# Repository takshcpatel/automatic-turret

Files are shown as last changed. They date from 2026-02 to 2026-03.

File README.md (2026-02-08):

# BOB THE GUN
This is an automatic turret inspired by the tf2's engineer's sentry gun. It detects and shoots threats if they do not comply from warning. I have made this project to learn about CAD, mechanical, computer vision, software->hardware communication, etc.

## Links
YouTube :- [Quack Robotics](https://www.youtube.com/@QuackRobotics)

Instagram :- [@quackrobotics](https://www.instagram.com/quackrobotics)

OnShape :- [OnShape CAD View](https://cad.onshape.com/documents/a227c9c3e91dedc730053277/w/3ffe9ea86f039fb92ebcc4d6/e/9ef318677793f062c9bceb51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)

Hackclub Blueprint :- [Bob the Gun](https://blueprint.hackclub.com/projects/9715)

Hackclub Flavortown :- [Bob the Gun](https://flavortown.hackclub.com/projects/8451)

Image of gun

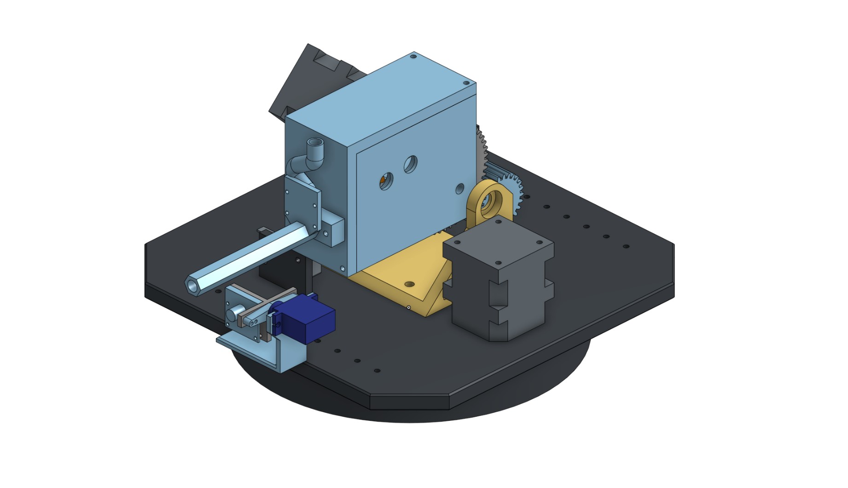
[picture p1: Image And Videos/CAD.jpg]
Image of CAD


## Working 
### Mechanical
This is an electric airsoft gun ( EAG ) type of mechanism mounted on a Pan / Tilt Mechanism. It is has a pan freedom of **∞**º and a tilt freedom of about 70-80º. Uses a lazy susan bearing for the infinite pan motion and the camera is connected to a SG-90 Servo for a independent tilt motion.

### Software 
The computer vision and calculations are done in the [RaspberryPi 5](https://www.raspberrypi.com/products/raspberry-pi-5/). It receives frames from the [RaspberryPi Camera 3 Wide](https://www.raspberrypi.com/products/camera-module-3/). (For now) It detects an object based on color (currently yellow) and calculates the direction to move. It has a deadzone system for determining when to shoot.

### Hardware controlling 
The Nema17 motors are controlled by an Arduino Uno with the CNC Shield V3. The Arduino is connected to the RPi using a standard USB Type A - USB Type B. The RPi sends G-Code like commands to the Arduino to control the motors. 

The human interface is controlled directly from the python script using either ethernet cable (restricts movement) or by Wi-Fi  local network, it works completely offline if you want it. 

### Power 
I have used a 12V+ 10000mAh Li-Po battery which connects to the CNC Shield and a XH-M404 Buck converter. The XH-M404 outputs 5.25V+ for the RaspberryPi and the Servo Motors.

## Use cases and applications
- If built with better parts and task specifics, it can be a use-case of riot-control. Sounds absurd but something like a paintball bullet or similar can be used to mark out people who are to be arrested for adding violence to the riot.

- Similarly, It can be used for drone defense if used with a guns / signal jammers / net launchers, etc.

- Can used for home security. This type can be equipped with rubber bullets so it hurts enough the robbers / intruders but doesn't. Of course it will have some kind of manual confirmation before shooting. 

- There can be other similar use case in many fields, mainly for security but more is yet to be discovered.

## Hardware List
|Item| Price  |
|--|--|
|RaspberryPi 5 8Gb  |99$|
|RaspberryPi Camera 3 Wide| 21$ |
|Arducam ToF Camera | 66$ |
|Orange NMC 11.1V 10000mAh | 44$ |
| 3D Printed Parts | Not accounted for
|Total|≈232$

## Libraries

- OpenCV

- NumPy

- PyQt5

## Licenses 
Just use it however you want in your project. This is just an educational project made so that I can learn different things. 

## Inspiration 
Cs2 Engineer

## Contact 
E-Mail :- takshcpatel@gmail.com
Discord :- mrcjoc

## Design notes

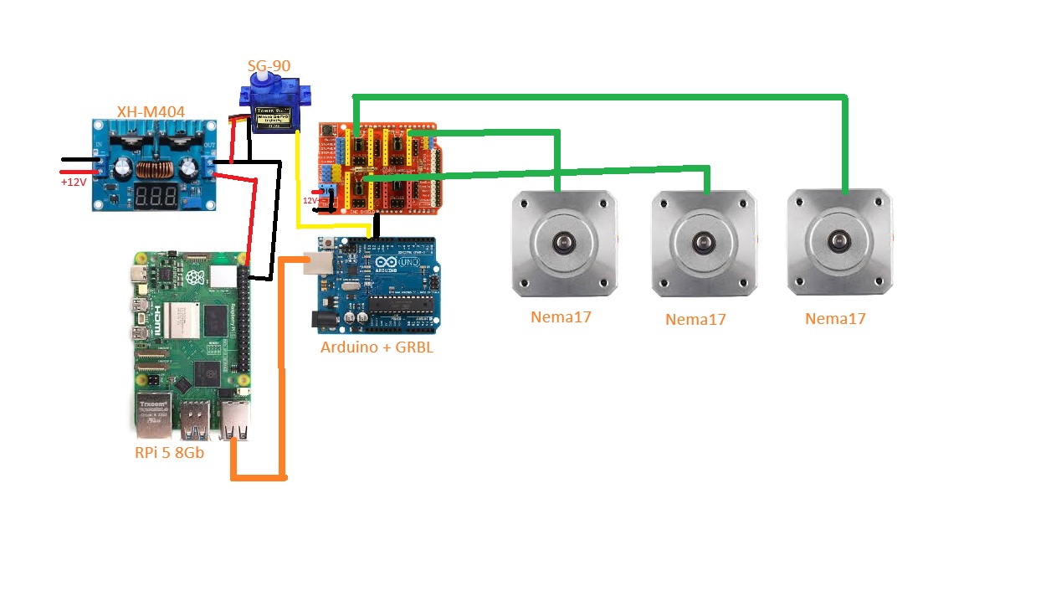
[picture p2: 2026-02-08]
Image And Videos/Pinout .jpg

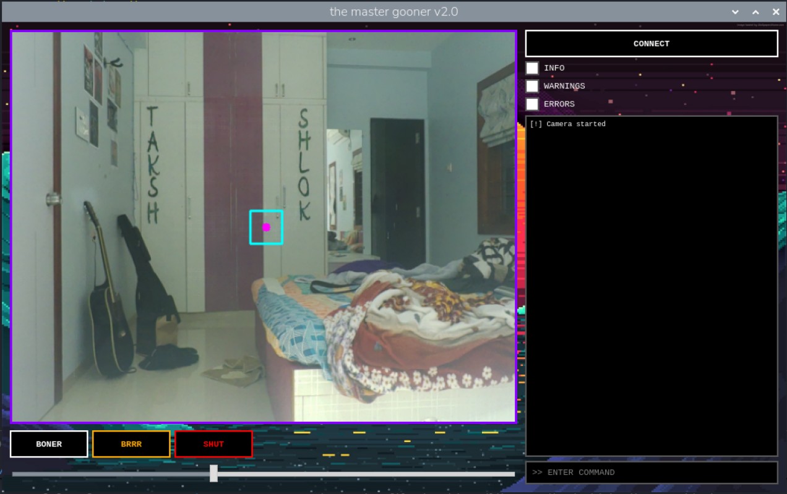
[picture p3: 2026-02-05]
Image And Videos/UI V2.0.jpg

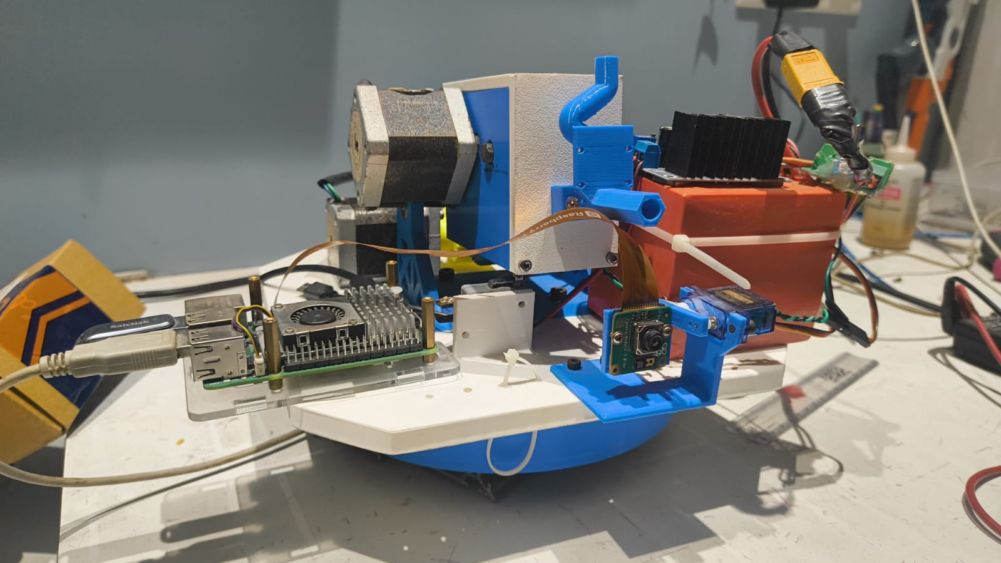
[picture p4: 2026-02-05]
Image And Videos/Photo #1.png

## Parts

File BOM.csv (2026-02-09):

Sr. No. | Name | Quantity | Price Single | Price Total USD | Price Total INR
1 | Raspberry Pi 5 8GB | 1 | ≈ 99.00$ | ≈ 99.00$ | 9000₹
2 | Raspberry Pi Camera 3 Wide | 1 | ≈ 21.00$ | ≈ 21.00$ | 1880₹
3 | Arducam Time of Flight Camera | 1 | ≈ 66.00$ | ≈ 66.00$ | 6000₹
4 | Orange NMC 18650 11.1V 10000mAh | 1 | ≈ 44.00$ | ≈ 44.00$ | 4000₹

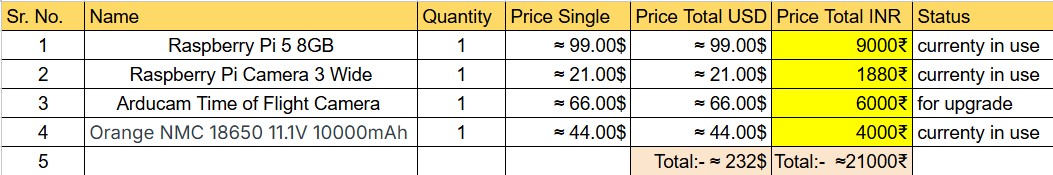
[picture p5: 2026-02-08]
BOM/BOM.jpg

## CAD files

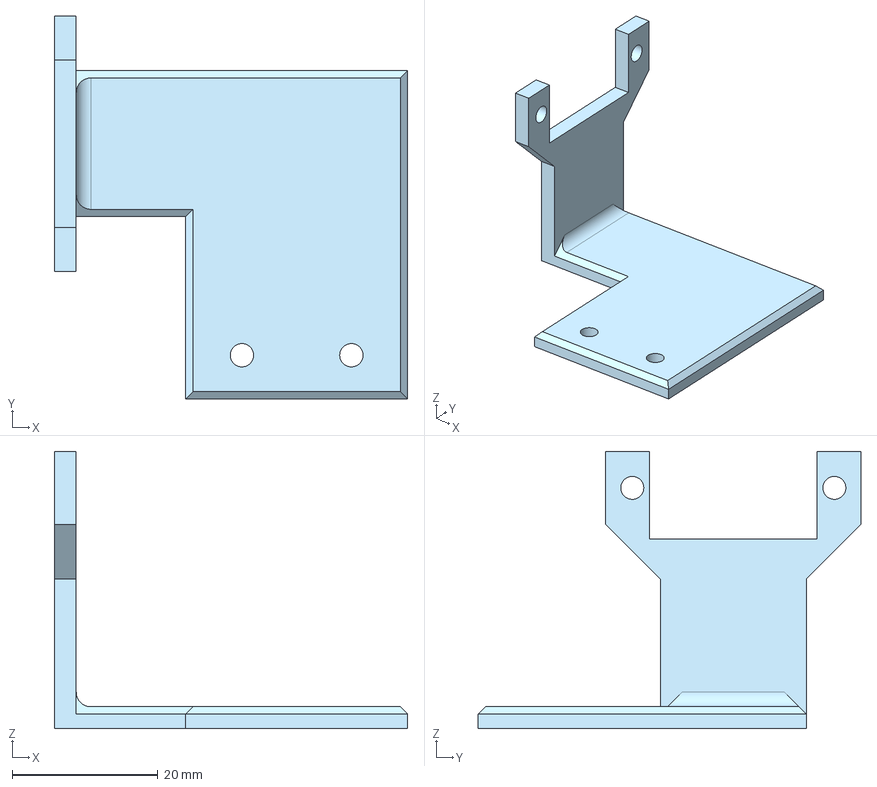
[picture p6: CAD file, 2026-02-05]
CAD Files/Pan/Camera hold/Servo Mount - Servo Base.step
48.4 x 52.5 x 38.0 mm

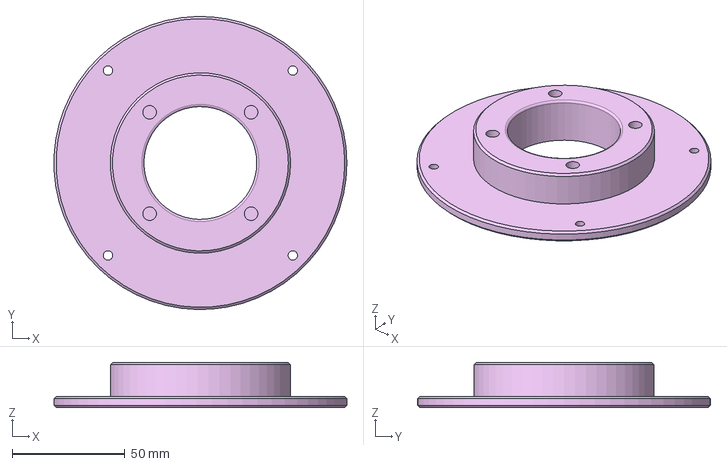
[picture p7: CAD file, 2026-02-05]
CAD Files/Pan/Moving Platform - Moving Platform.step
129.9 x 130.0 x 20.0 mm

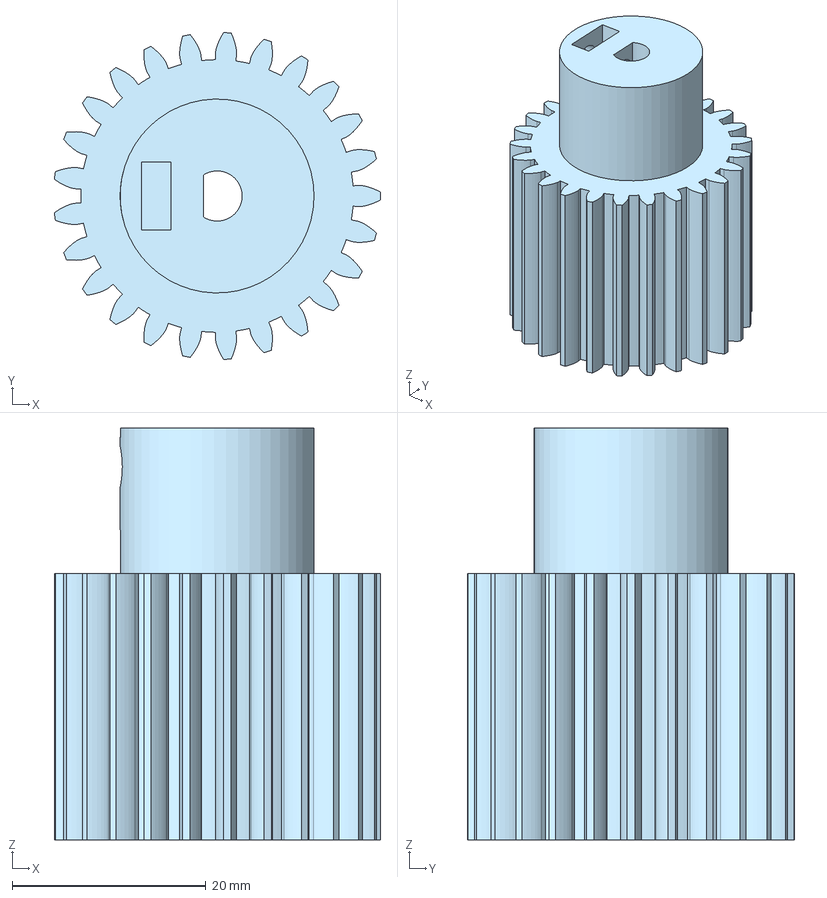
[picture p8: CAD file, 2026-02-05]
CAD Files/Tilt/Tilt Gear Train - Spur 1.25M 25T.step
33.7 x 33.7 x 42.5 mm

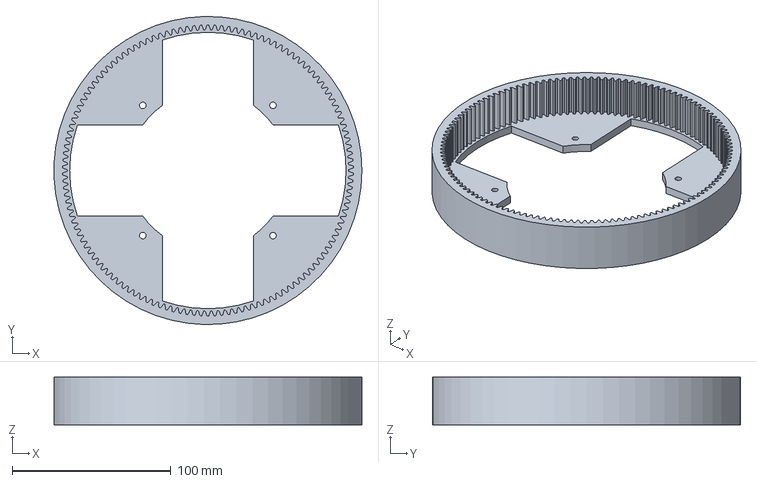
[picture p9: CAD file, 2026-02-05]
CAD Files/Pan/Base (1) - Base.step
193.9 x 193.9 x 30.0 mm

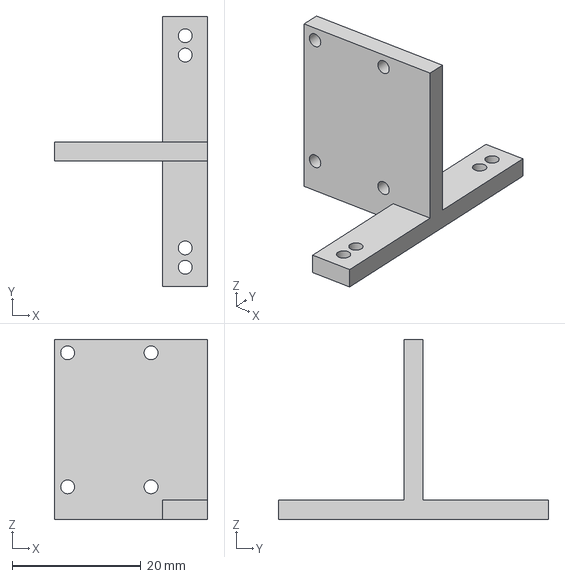
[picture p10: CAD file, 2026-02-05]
CAD Files/Pan/Camera hold/Servo Mount - Servo-Cam Mount.step
23.9 x 42.0 x 28.0 mm

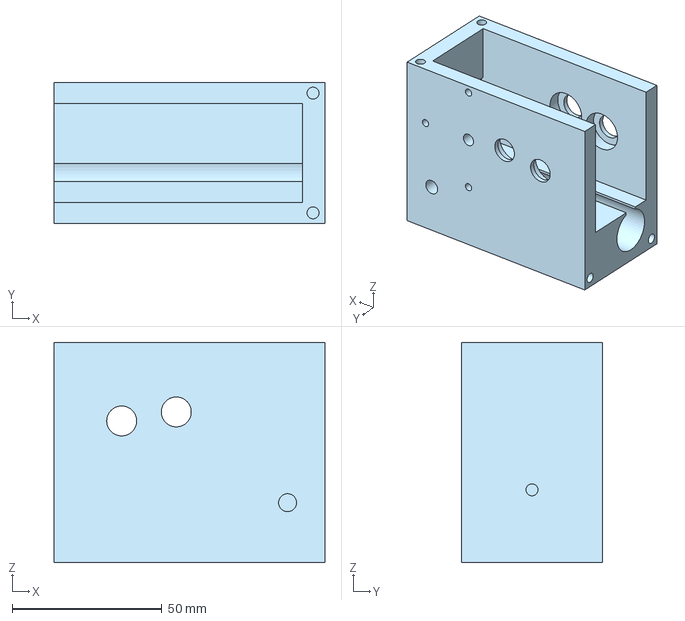
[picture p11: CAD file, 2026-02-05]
CAD Files/Tilt/Gun/Bottom Link - Body.step
90.5 x 47.0 x 73.5 mm

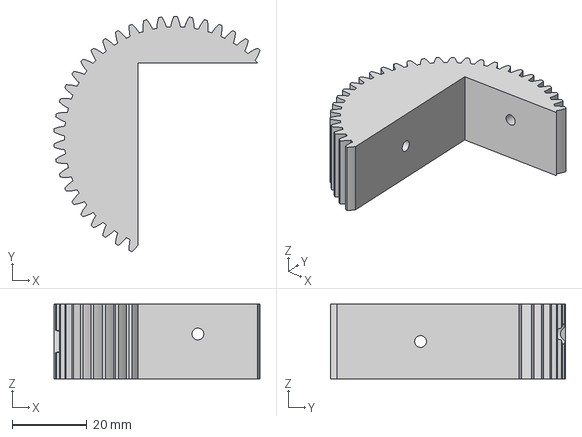
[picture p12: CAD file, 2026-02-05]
CAD Files/Tilt/Tilt Gear Train - Spur 1.25M 50T.step
55.0 x 62.9 x 20.0 mm

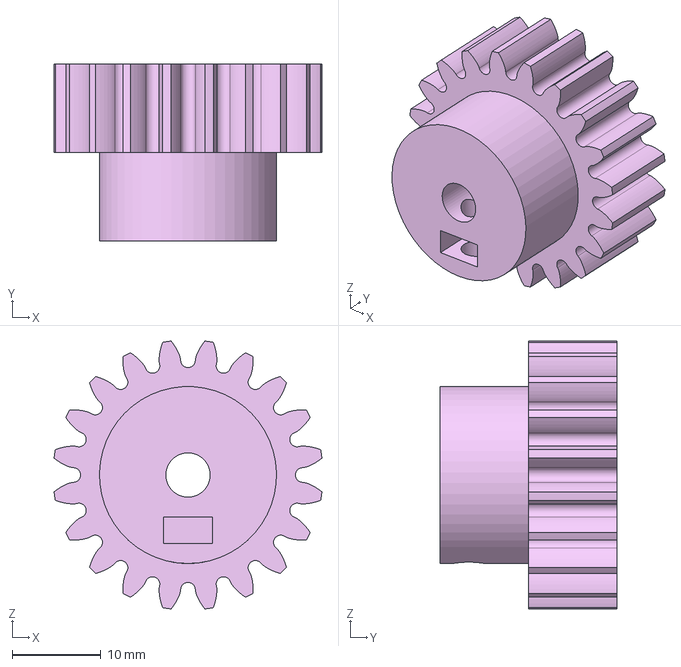
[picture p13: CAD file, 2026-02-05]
CAD Files/Pan/MoveGear - Spur gear (20 teeth).step
30.3 x 20.0 x 30.3 mm

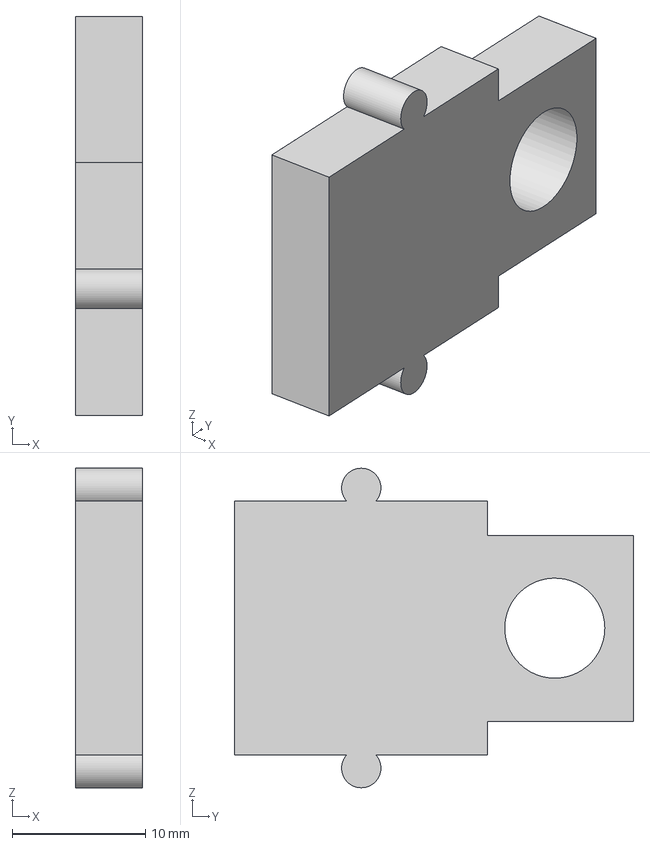
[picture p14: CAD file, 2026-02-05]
CAD Files/Tilt/Gun/Face plate - TPU Damper.step
5.00 x 29.9 x 24.0 mm

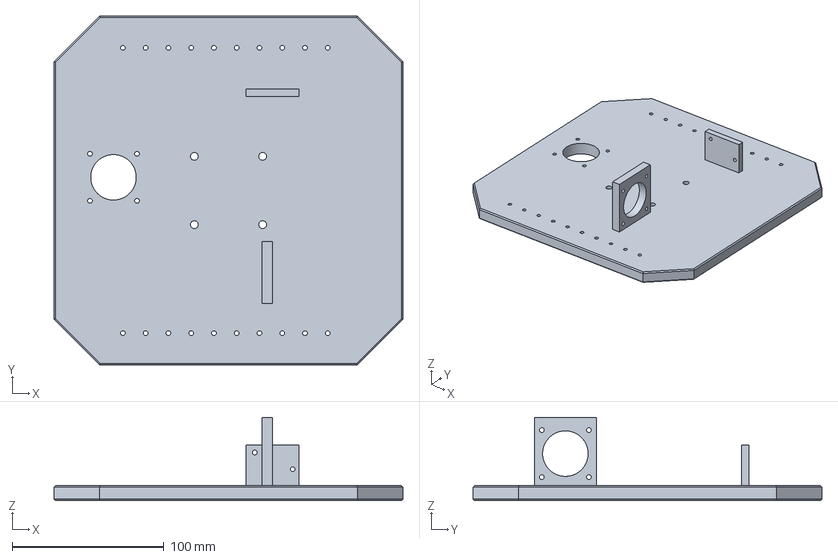
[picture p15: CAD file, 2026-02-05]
CAD Files/Pan/Moving Attachment - Moving Attachment.step
230.0 x 230.0 x 55.0 mm

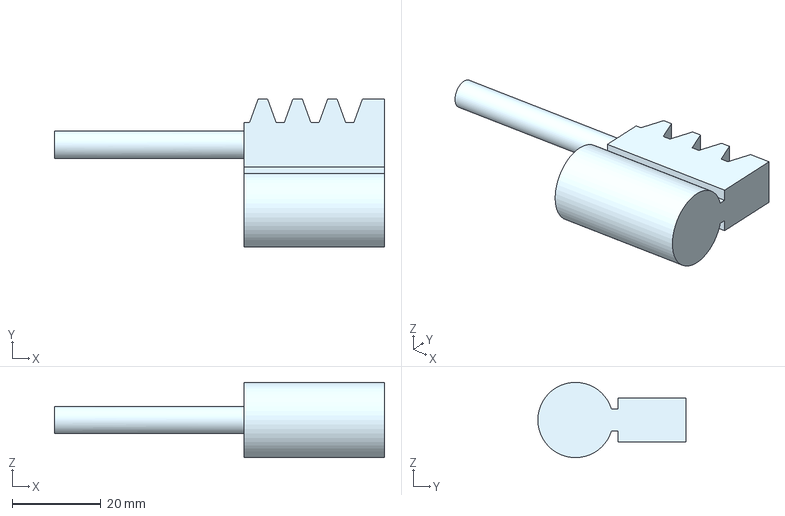
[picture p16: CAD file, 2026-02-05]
CAD Files/Tilt/Gun/GearTrain - Rack (4 teeth).step
74.6 x 33.5 x 17.0 mm

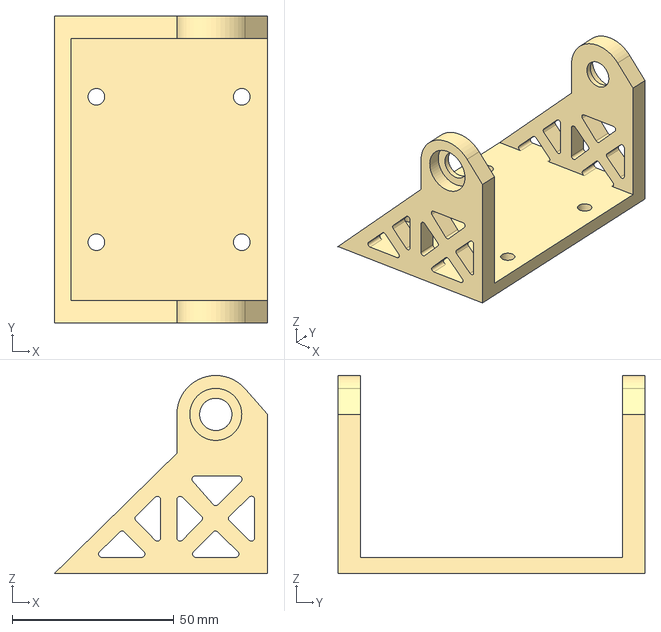
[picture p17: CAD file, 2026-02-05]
CAD Files/Pan/U-Hold - U-Hold.step
66.0 x 95.0 x 61.3 mm

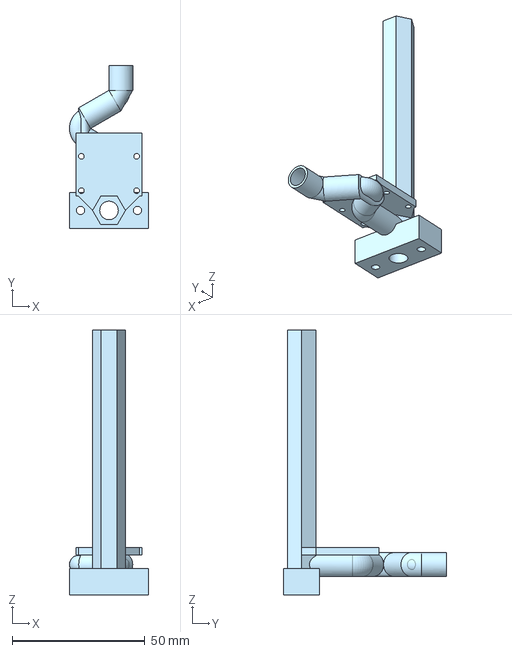
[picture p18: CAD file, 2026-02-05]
CAD Files/Tilt/Gun/Barrel - Part 1.step
30.0 x 61.6 x 100.0 mm

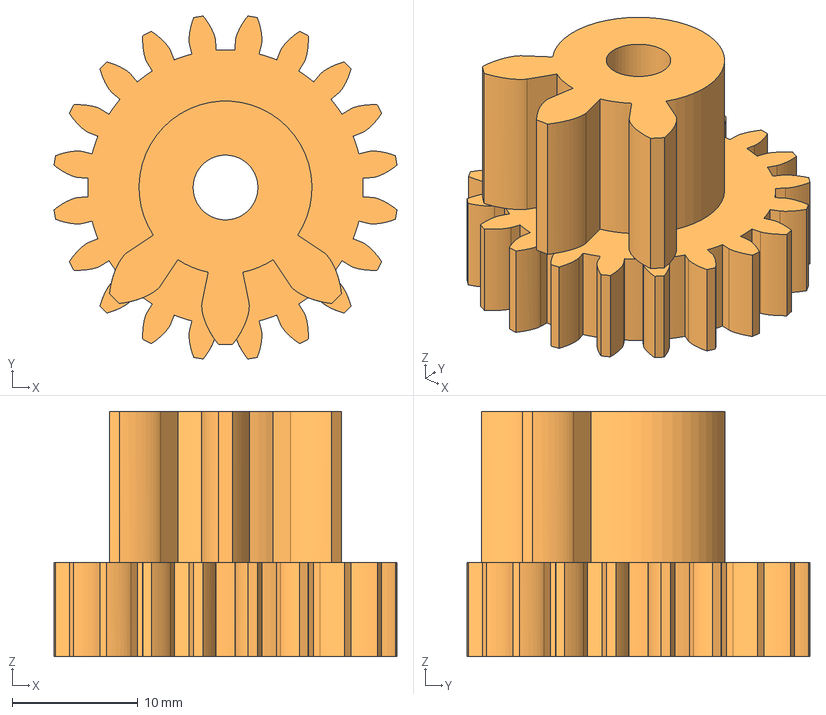
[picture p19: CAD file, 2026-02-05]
CAD Files/Tilt/Gun/GearTrain - Spur 2.5M 8T.step
27.3 x 27.3 x 19.5 mm

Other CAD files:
CAD Files/Tilt/Gun/GearTrain - Spur 1.25M 10T.step
CAD Files/Tilt/Gun/Face plate - Face Plate.step
CAD Files/Tilt/Gun/GearTrain - Spur 1.25M 10T (2).step
CAD Files/Tilt/Gun/GearTrain - Spur 1.25M 10T (1).step

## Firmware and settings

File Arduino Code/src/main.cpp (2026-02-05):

#include <AccelStepper.h>
#include <Servo.h>
#include <Arduino.h> 

#define X_STEP_PIN 2
#define X_DIR_PIN 5

#define Y_STEP_PIN 3
#define Y_DIR_PIN 6

#define Z_STEP_PIN 4
#define Z_DIR_PIN 7

#define X_LIMIT_PIN 9
#define ALL_ENABLE_PIN 8
#define SERVO_PIN 11

Servo tiltServo;

const float ANG_PER_STEP = 0.1125;

int pan_angle = 0;
int tilt_angle = 0;
int tiltServo_angle = 93;

bool LIMIT_STATUS = false;
bool SNAP_ACTIVE = false;
bool CUMSHOT_READY = false;

AccelStepper stepperX(AccelStepper::DRIVER, X_STEP_PIN, X_DIR_PIN);
AccelStepper stepperY(AccelStepper::DRIVER, Y_STEP_PIN, Y_DIR_PIN);
AccelStepper stepperZ(AccelStepper::DRIVER, Z_STEP_PIN, Z_DIR_PIN);

char rxBuf[32];
byte rxIdx = 0;

void homeX();
void snapMoveXY(int x_deg, int y_deg);
void cumshot();
void parseGcode(char *cmd);

long angleToSteps(int deg)
{
  return lround((float)deg / ANG_PER_STEP);
}

void setup()
{
  Serial.begin(115200);

  tiltServo.attach(SERVO_PIN);
  tiltServo.write(tiltServo_angle);

  pinMode(X_LIMIT_PIN, INPUT_PULLUP);
  pinMode(ALL_ENABLE_PIN, OUTPUT);
  digitalWrite(ALL_ENABLE_PIN, LOW);

  stepperX.setMaxSpeed(5000);
  stepperX.setAcceleration(800);

  stepperY.setMaxSpeed(4000);
  stepperY.setAcceleration(800);

  stepperZ.setMaxSpeed(5000);
  stepperZ.setAcceleration(300);

  delay(2000);
  homeX();
}

void loop()
{
  if (LIMIT_STATUS){
    homeX();
  }
  if (!SNAP_ACTIVE)
  {
    stepperX.run();
    stepperY.run();
  }

  while (Serial.available())
  {
    char c = Serial.read();
    if (c == '\n')
    {
      rxBuf[rxIdx] = '\0';
      rxIdx = 0;
      parseGcode(rxBuf);
    }
    else if (rxIdx < sizeof(rxBuf) - 1)
    {
      rxBuf[rxIdx++] = c;
    }
  }
  cumshot();
}

void homeX()
{
  stepperY.setSpeed(-400);
  while (digitalRead(X_LIMIT_PIN) == LOW)
  {
    stepperY.runSpeed();
  }

  tiltServo.write(93);
  tiltServo_angle = 93;
  stepperY.move(40);
  stepperY.runToPosition();
  tilt_angle = 0;
  LIMIT_STATUS = false;
}

int tiltToServo(int tilt_deg)
{
  tilt_deg = constrain(tilt_deg, 0, 70);
  return 93 + (tilt_deg * 87) / 70;
}

void snapMoveXY(int x_deg, int y_deg, int x_speed, int y_speed)
{
  SNAP_ACTIVE = true;
  
  long sx = angleToSteps(x_deg) * 6.5;
  long tx = stepperX.currentPosition() + sx;

  long sy = angleToSteps(y_deg) * 2;
  long ty = stepperY.currentPosition() + sy;

  stepperX.setSpeed((sx > 0) ? x_speed : -x_speed);
  stepperY.setSpeed((sy > 0) ? y_speed : -y_speed);

  if (tilt_angle + y_deg >= 0)
  {
    while (stepperX.currentPosition() != tx ||
           stepperY.currentPosition() != ty)
    {      
      if (digitalRead(X_LIMIT_PIN) == HIGH)
      {
        stepperX.stop();
        stepperY.stop();
        LIMIT_STATUS = true;
        break;
      }
      if (stepperX.currentPosition() != tx) stepperX.runSpeed();
      if (stepperY.currentPosition() != ty) stepperY.runSpeed();

      cumshot();
    }

    tilt_angle += y_deg;
    tilt_angle = constrain(tilt_angle, 0, 70);
  }
  else
  {
    tilt_angle = 0;
    // Serial.println("[!!] Min Tilt Reached ignoring remaining path");
  }

  stepperX.setSpeed(0);
  stepperY.setSpeed(0);
  pan_angle += x_deg;

  tiltServo_angle = tiltToServo(tilt_angle);
  tiltServo.write(tiltServo_angle);

  SNAP_ACTIVE = false;
}

void cumshot(){
  if(CUMSHOT_READY){
    stepperZ.setSpeed(300);
    stepperZ.runSpeed();
  } else {
    stepperZ.setSpeed(0);
    stepperZ.runSpeed();
  }
}

void disableBonner()
{
  digitalWrite(ALL_ENABLE_PIN, HIGH);
}

void enableBonner()
{
  digitalWrite(ALL_ENABLE_PIN, LOW);
}

void parseGcode(char *cmd)
{
  int g = -1, x = 0, y = 0, x_speed = 0, y_speed = 0;
  int count = sscanf(cmd, "G%d %d %d %d %d", &g, &x, &y, &x_speed, &y_speed);
  if (count < 1) return;

  else if (g == 2 && count == 5)
    snapMoveXY(x, y, x_speed, y_speed);
  else if (g == 11)
    CUMSHOT_READY = true;
  else if (g == 12)
    CUMSHOT_READY = false;
  else if (g == 28)
    homeX();
  else if (g == 98)
    enableBonner();
  else if (g == 99)
    disableBonner();
}

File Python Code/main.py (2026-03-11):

import time
from PyQt5.QtWidgets import (
    QApplication,
    QWidget,
    QVBoxLayout,
    QGroupBox,
    QHBoxLayout,
    QPushButton,
    QPlainTextEdit,
    QCheckBox,
    QLineEdit,
    QLabel,
    QSlider,
)

from PyQt5.QtGui import QImage, QPixmap, QBrush
from PyQt5.QtCore import Qt, QTimer, pyqtSignal
from controller import CameraWorker
import cv2
import sys
import serial


class Window(QWidget):
    deadzone_value = pyqtSignal(int)

    def __init__(self):
        super().__init__()

        self.camera = CameraWorker()
        self.camera.frame_ready.connect(self.on_new_frame)
        self.camera.MODE.connect(self.update_mode)
        self.camera.err_signal.connect(self.send_tracking)
        self.camera.status.connect(self.log)
        self.camera.ATTACK.connect(self.attack_manager)

        self.current_mode = 0

        self.camera.start()
        self.deadzone_value.connect(self.camera.update_deadzone)
        
        self.previous_attack_state = False  

        self.setWindowTitle("the master gooner v2.0")
        self.resize(1000, 600)
        
        import os
        bg_path = os.path.join(os.path.dirname(__file__), "Background.jpg")
        bg_pixmap = QPixmap(bg_path)
        if not bg_pixmap.isNull():
            scaled_pixmap = bg_pixmap.scaled(1000, 600, Qt.IgnoreAspectRatio, Qt.SmoothTransformation)
            palette = self.palette()
            palette.setBrush(self.backgroundRole(), QBrush(scaled_pixmap))
            self.setPalette(palette)
        
        self.setStyleSheet(
            "color: #ffffff; font-family: 'Courier New', monospace; font-size: 11px;"
        )

        self.BTN_Connect = QPushButton("CONNECT")
        self.BTN_Connect.setMinimumSize(100, 35)
        self.apply_retro_button(self.BTN_Connect, "#ffffff", "#000")
        self.BTN_Connect.setCheckable(True)

        self.PBTN_Bonner = QPushButton("BONER")
        self.PBTN_Bonner.setMinimumSize(100, 35)
        self.apply_retro_button(self.PBTN_Bonner, "#ffffff", "#000")
        self.PBTN_Bonner.setCheckable(True)
        self.PBTN_Bonner.setChecked(True)

        self.BTN_START_SHOOT = QPushButton("BRRR")
        self.BTN_START_SHOOT.setMinimumSize(100, 35)
        self.apply_retro_button(self.BTN_START_SHOOT, "#ffaa00", "#000")

        self.BTN_STOP_SHOOT = QPushButton("SHUT")
        self.BTN_STOP_SHOOT.setMinimumSize(100, 35)
        self.apply_retro_button(self.BTN_STOP_SHOOT, "#ff0000", "#000")

        self.BTN_STOP_SHOOT.clicked.connect(self.shoot_stop_manager)
        self.BTN_START_SHOOT.clicked.connect(self.shoot_start_manager)

        self.PBTN_Bonner.setCheckable(True)
        self.PBTN_Bonner.setChecked(True)
        self.PBTN_Bonner.toggled.connect(self.bonnerManager)

        self.SLIDER_Deadzone = QSlider(Qt.Horizontal)
        self.SLIDER_Deadzone.setRange(0, 50)
        self.SLIDER_Deadzone.setSingleStep(1)
        self.SLIDER_Deadzone.setValue(20)
        self.SLIDER_Deadzone.valueChanged.connect(self.deadzone_value.emit)

        self.video_label = QLabel()
        self.video_label.setMinimumSize(480, 360)
        self.video_label.setStyleSheet("background-color: #000; border: 3px solid #8800ff;")

        self.Console = QPlainTextEdit()
        self.Console.setMinimumSize(320, 360)
        self.Console.setReadOnly(True)
        self.Console.setStyleSheet(
            "background-color: #000; color: #ffffff; border: 2px solid #555; "
            "font-family: 'Courier New', monospace; font-size: 9px;"
        )
        self.command_input = QLineEdit()
        self.command_input.setPlaceholderText(">> ENTER COMMAND")
        self.command_input.setStyleSheet(
            "background-color: #000; color: #ffffff; border: 2px solid #555; "
            "font-family: 'Courier New', monospace; padding: 5px;"
        )

        layout_main = QHBoxLayout()
        layout_main.setContentsMargins(10, 10, 10, 10)
        layout_main.setSpacing(10)

        layout_video_section = QVBoxLayout()
        layout_video_section.setContentsMargins(0, 0, 0, 0)
        layout_video_section.setSpacing(8)
        layout_video_section.addWidget(self.video_label)
        
        layout_controls = QHBoxLayout()
        layout_controls.setContentsMargins(0, 0, 0, 0)
        layout_controls.setSpacing(5)
        layout_controls.addWidget(self.PBTN_Bonner)
        layout_controls.addWidget(self.BTN_START_SHOOT)
        layout_controls.addWidget(self.BTN_STOP_SHOOT)
        layout_controls.addStretch()
        
        layout_video_section.addLayout(layout_controls)
        layout_video_section.addWidget(self.SLIDER_Deadzone)

        layout_console = QVBoxLayout()
        layout_console.setContentsMargins(0, 0, 0, 0)
        layout_console.setSpacing(5)

        self.checkbox_lvl1 = QCheckBox("INFO")
        self.checkbox_lvl2 = QCheckBox("WARNINGS")
        self.checkbox_lvl3 = QCheckBox("ERRORS")
        self.checkbox_lvl1.setStyleSheet("QCheckBox { color: #ffffff; } QCheckBox::indicator { border: 2px solid #555; width: 14px; height: 14px; } QCheckBox::indicator:checked { background-color: #ffffff; }")
        self.checkbox_lvl2.setStyleSheet("QCheckBox { color: #ffffff; } QCheckBox::indicator { border: 2px solid #555; width: 14px; height: 14px; } QCheckBox::indicator:checked { background-color: #ffffff; }")
        self.checkbox_lvl3.setStyleSheet("QCheckBox { color: #ffffff; } QCheckBox::indicator { border: 2px solid #555; width: 14px; height: 14px; } QCheckBox::indicator:checked { background-color: #ffffff; }")
        
        layout_console.addWidget(self.BTN_Connect)
        layout_console.addWidget(self.checkbox_lvl1)
        layout_console.addWidget(self.checkbox_lvl2)
        layout_console.addWidget(self.checkbox_lvl3)
        layout_console.addWidget(self.Console)
        layout_console.addWidget(self.command_input)

        self.command_input.returnPressed.connect(
            lambda: self.send_command(self.command_input.text().strip())
        )
        
        layout_main.addLayout(layout_video_section, 2)
        layout_main.addLayout(layout_console, 1)
        self.setLayout(layout_main)

        self.checkbox_lvl1.setChecked(True)
        self.checkbox_lvl2.setChecked(True)
        self.checkbox_lvl3.setChecked(True)

        self.ser = None
        self.timer = QTimer()
        self.timer.timeout.connect(self.read_serial)
        self.BTN_Connect.toggled.connect(self.connect_arduino)
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

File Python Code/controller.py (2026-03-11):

from PyQt5.QtCore import QThread, pyqtSignal, pyqtSlot

from picamera2 import Picamera2
from libcamera import Transform

import cv2
import numpy as np
import time

import threading


class CameraWorker(QThread):
    frame_ready = pyqtSignal(object)
    err_signal = pyqtSignal(int, int, int, int)
    status = pyqtSignal(str)
    ATTACK = pyqtSignal(bool)
    MODE = pyqtSignal(str)

    X_STEP_SIZE = 0
    Y_STEP_SIZE = 0

    def __init__(self):
        super().__init__()
        self.running = False
        self.picam2 = None
        self.SLIDER_deadzone = 20

        self.attack_timer_start = None
        self.attack_emitted = False
        self.attack_timeout = 1

        self.X_SPEED = 4000
        self.Y_SPEED = 4000

        self.current_mode = "SCANNING"

    def run(self):
        self.picam2 = Picamera2()
        self.picam2.configure(
            self.picam2.create_preview_configuration(
                main={"format": "BGR888", "size": (640, 480)},
                transform=Transform(rotation=180),
            )
        )

        self.picam2.start()
        time.sleep(1.5)

        self.picam2.set_controls({"AfMode": 2})
        self.status.emit("[!] Camera started")
        self.running = True

        while self.running:
            frame = self.picam2.capture_array()
            frame = cv2.cvtColor(frame, cv2.COLOR_BGR2RGB)

            h, w, _ = frame.shape
            screen_center = (w // 2, h // 2)

            err_x, err_y = 0, 0
            target_found = False

            hsv = cv2.cvtColor(frame, cv2.COLOR_BGR2HSV)
            lower_yellow = np.array([20, 100, 100])
            upper_yellow = np.array([30, 255, 255])

            mask = cv2.inRange(hsv, lower_yellow, upper_yellow)
            mask = cv2.GaussianBlur(mask, (5, 5), 0)
            mask = cv2.erode(mask, None, iterations=2)
            mask = cv2.dilate(mask, None, iterations=2)

            contours, _ = cv2.findContours(
                mask, cv2.RETR_EXTERNAL, cv2.CHAIN_APPROX_SIMPLE
            )

            cv2.rectangle(frame, (w//2 - self.SLIDER_deadzone, h//2 - self.SLIDER_deadzone),
                                  (w//2 + self.SLIDER_deadzone, h//2 + self.SLIDER_deadzone), (255, 255, 0), 2)
            cv2.circle(frame, screen_center, 5, (255, 0, 255), -1)

            in_deadzone = False
            if contours:
                largest = max(contours, key=cv2.contourArea)
                if cv2.contourArea(largest) > 500:
                    target_found = True
                    x, y, bw, bh = cv2.boundingRect(largest)
                    obj_center = (x + bw // 2, y + bh // 2)

                    raw_err_x = (obj_center[0] - screen_center[0])
                    raw_err_y = (obj_center[1] - screen_center[1])

                    if abs(raw_err_x) < self.SLIDER_deadzone:
                        in_deadzone = True
                        err_x = 0
                    if abs(raw_err_y) < self.SLIDER_deadzone:
                        in_deadzone = True
                        err_y = 0
                    else:
                        err_x = raw_err_x
                        err_y = raw_err_y

                    if abs(err_x) < 50 and abs(err_x) > 0:
                        X_STEP_SIZE = 1
                        self.X_SPEED = 4000
                    if abs(err_x) >= 50 and abs(err_x) < 100:
                        X_STEP_SIZE = 2
                        self.X_SPEED = 4000
                    if abs(err_x) >= 100 and abs(err_x) < 200:
                        X_STEP_SIZE = 3
                        self.X_SPEED = 5000
                    if abs(err_x) >= 200:
                        X_STEP_SIZE = 3
                        self.X_SPEED = 5000
                        
                    if abs(err_y) < 50 and abs(err_y) > 0:
                        Y_STEP_SIZE = 1
                        self.Y_SPEED = 3000
                    if abs(err_y) >= 50 and abs(err_y) < 100:
                        Y_STEP_SIZE = 2
                        self.Y_SPEED = 3000
                    if abs(err_y) >= 100 and abs(err_y) < 200:
                        Y_STEP_SIZE = 3
                        self.Y_SPEED = 4000
                    if abs(err_y) >= 200:
                        Y_STEP_SIZE = 3
                        self.Y_SPEED = 4000

                    if err_x > 0:
                        err_x = -X_STEP_SIZE
                    elif err_x < 0:
                        err_x = X_STEP_SIZE
                    if err_y > 0:
                        err_y = -Y_STEP_SIZE
                    elif err_y < 0:
                        err_y = Y_STEP_SIZE

                    cv2.rectangle(frame, (x, y), (x + bw, y + bh), (0, 255, 0), 2)
                    cv2.circle(frame, obj_center, 3, (0, 0, 255), -1)
                    cv2.line(frame, screen_center, obj_center, (255, 0, 0), 2)

            new_mode = "TRACKING" if target_found else "SCANNING"
            if new_mode != self.current_mode:
                self.current_mode = new_mode
                self.MODE.emit(new_mode)

            if in_deadzone:
                if self.attack_timer_start is None:
                    self.attack_timer_start = time.monotonic()
                elif not self.attack_emitted and (time.monotonic() - self.attack_timer_start) >= self.attack_timeout:
                    self.attack_emitted = True
                    self.ATTACK.emit(True)
            else:
                if self.attack_timer_start is not None or self.attack_emitted:
                    self.attack_timer_start = None
                    self.attack_emitted = False
                    self.ATTACK.emit(False)

            self.err_signal.emit(err_x, err_y, self.X_SPEED, self.Y_SPEED)
            self.frame_ready.emit(frame)
            time.sleep(0.01)

        self.picam2.stop()
        self.status.emit("[!] Camera stopped")

    @pyqtSlot(int)
    def update_deadzone(self, value):
        self.SLIDER_deadzone = value
        self.status.emit(f"[!] Deadzone updated to: {value}")

    def stop(self):
        self.running = False

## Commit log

2025-12-13 Added first code
    Added the code I wrote so far, it has :-
    - Homing
    - Move to x angle
    - PyQt5 GUI
    - GUI shows notifications from controller with selectable levels of notifications to see
2025-12-13 Revise README with comprehensive project details
    Expanded project description and added detailed sections on features, system architecture, technologies used, current status, and license.
2025-12-14 Added GCODE and Serial i/p from HMI
    Added GCODE support for the motors. Now G0 is incremental and G1 is absolute. Example :- G0 10 10 or G1 160 25
    Added text bar where you can send the GCODE to the Arduino from your HMI.
2025-12-16 added simple camera stuff
2025-12-16 Added camera to GUI and improved
    added camera feed to gui ( with cv2 processing )
2025-12-18 added deadzone slider
    added deadzone slider to gui and made it update on opencv draw frame to show user the outline of the deadzone.
2026-01-31 made tracking better with changing step sizes depending on distances and some other small fixes
    [main.py]
2026-02-05 fixed directory
    [BOM.csv, Barrel - Part 1.step, Base (1) - Base.step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]
2026-02-08 Uploaded latest screenshots and better BOM
2026-02-08 Added new bom
2026-02-08 updated BOM
2026-03-11 fixing directories
    [BOM.csv, Barrel - Part 1.step, Base (1) - Base.step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]
2026-03-11 fixing directory pt.2
    [BOM.csv, Barrel - Part 1.step, Base (1) - Base.step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]
2026-03-11 Added FPS on frame, Added Target lockon indicator
2026-03-11 Added scanning but doesnt work reliably, will fix after exams
    [controller.py, main.py]
2026-03-11 Revert "Added scanning but doesnt work reliably, will fix after exams"
    This reverts commit 25524ea09a5d38035ec9d119442f3f57adcf566d.
    [controller.py, main.py]
2026-03-11 Revert "fixed the directory"
    This reverts commit 936160878343d46e0942295b3d4854873d83cffb.
    [main.cpp]
2026-03-11 fixed directory, i hate git and love it
    [controller.py]
